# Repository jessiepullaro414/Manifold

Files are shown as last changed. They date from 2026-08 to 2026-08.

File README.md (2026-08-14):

# Manifold — KiCad schematic + PCB

Companion KiCad project for "Manifold", an Arduino Nano inspired (pinout/
form-factor only — not an official Arduino product, and not Arduino-IDE
compatible) 12V-powered board built from automotive/high-temp-rated parts
for engine-bay environments.

## Opening it

Open `Manifold.kicad_pro` in KiCad 6, 7, or 8. Everything the schematic needs
(all symbols) is embedded in `Manifold.kicad_sch` itself — no external symbol
libraries required to open and view it.

Both the schematic and `Manifold.kicad_pcb` are kept in KiCad's **current
native format** (not just an older-but-compatible one) — see "File format" below.

J1's footprint (TE AMPSEAL 776180-1) lives in this project too —
[`fp-lib-table`](fp-lib-table) registers it under the library nickname
`TE_AMPSEAL_776180-1`, pointing at [`footprints/TE_AMPSEAL_776180-1.pretty/`](footprints/TE_AMPSEAL_776180-1.pretty)
via `${KIPRJMOD}` (KiCad's "this project's folder" variable) — so it resolves
automatically for anyone who opens this project, without depending on where
it was originally downloaded to.

Same pattern on the schematic side: [`sym-lib-table`](sym-lib-table) registers
this project's own custom parts under the nickname `Manifold`, pointing at
[`Manifold.kicad_sym`](Manifold.kicad_sym) (both regenerated by `build_schematic.py` -
don't hand-edit either). The schematic still embeds every symbol inline too
(so it opens/nets fine even without this), but a real external library file
is what lets KiCad's own "Add Symbol" browser find `Manifold:*` parts, and is
what a from-scratch `kicad-cli sch erc` needs to not flag every single part
as "library not included in configuration".

## Building it

[`build.py`](build.py) runs the whole real pipeline in order — schematic
generation, PCB placement, autorouting, DRC — the same four scripts
described in "Routing it" and "How the schematic is built" below, just
chained together:

```
python build.py                 # full pipeline
python build.py --skip-route    # skip the slow FreeRouting pass
```

## Checking it

[`run_drc.py`](run_drc.py) runs `kicad-cli pcb drc` against `Manifold.kicad_pcb`
(or any other `.kicad_pcb` passed as an argument) and prints a readable report from
the JSON it produces — unconnected-item count (expected on this unrouted board) plus
every other violation type, grouped, with the actual offending items and positions,
not just per-type counts. `build_pcb.py` also runs DRC as its own last step, but only
prints counts; reach for this when you need the detail behind one of those counts.

```
python run_drc.py
python run_drc.py path/to/other.kicad_pcb
```

`kicad-cli sch erc Manifold.kicad_sch` is the schematic-side equivalent.
It went from **388 violations to 4** during a real triage pass (not just a
recount) - see "Rotated-footprint pad shapes" below and
[[kicad-file-generation-gotchas]] for the technical detail on each fix:

- 259 `endpoint_off_grid` - every symbol placement now snaps to KiCad's
  0.05in (1.27mm) schematic grid.
- 70 `lib_symbol_issues` - added a real `Manifold.kicad_sym` + `sym-lib-table`
  entry (this project's custom parts were only ever embedded inline in the
  schematic before, with no external library file backing them - fine for
  KiCad to open/net-list, not fine for its "library not found" check or for
  inserting a fresh instance from the symbol browser).
- 25 `label_dangling` + 25 `no_connect_connected` - U1's 25 spare MCU pins
  now get a real no-connect flag instead of a same-named, inherently
  one-off local label.
- 3 `isolated_pin_label` - same fix, applied to 3 individually-unused pins
  elsewhere (U2's PG, U4's NC, J2's NC) via a new `('nc',)` `place()` mode.
- 1 `pin_to_pin` - J1's +5V/+3V3 pins were typed `power_out` (implying the
  *connector* generates power), conflicting with U4's real LDO output on
  the same net - retyped `passive` (a connector pin exposing a rail isn't
  a second source of it).

**The remaining 4 are genuine, expected ERC characteristics, not bugs** -
each one is ERC's pin-type-based "is this driven?" check failing to trace
through a passive network or off-board source, not a real missing
connection:

- `+5V`, `VDDA`, and U2's `VIN` each show `power_pin_not_driven` because
  their real source sits on the far side of an LC filter (L1), a ferrite
  (L2), or a MOSFET (Q1) - none of which have a `power_out`-type pin to
  point to, since ERC doesn't trace continuity through passives.
- J2's `SWCLK` shows `pin_not_driven` because it's genuinely driven
  off-sheet, by an external debug probe.

If you regenerate and see anything **other than these same 4**, treat it
as a real regression, not baseline noise.

## Buck feedback divider - a real bug found in final review

R2/R3 (U2's FB divider) used to be 10k/3.3k, solving TI's own formula
(`Vout = VREF x (RFBT/RFBB + 1)`, VREF = 1V nominal per LMR33630-Q1's
datasheet Section 8.2.2.3) to **~4.03V, not 5V** - a real, roughly-1V-low
output, not a rounding nitpick. This mattered because that rail is exposed
on J1 as a Nano-compatible +5V pin for **external peripherals** - anything
expecting real 5V plugged into it would have been under-powered or
malfunctioned outright, and it ate into U4's LDO dropout margin too.

Fixed by solving for RFBB with RFBT held at 10k: `10k / (5V/1V - 1) = 2.5k`,
using the nearest standard E96 value, **2.49k** - which is suspiciously
exactly TI's own worked-example RFBB (24.9k, for their 100k/24.9k 5V
divider) scaled down by 10x, suggesting 3.3k was a substitution/typo
somewhere rather than a deliberate choice. New value gives ~5.02V.

## File format

`kiutils` (the library both generators use) writes the older v6-era schema by
default — version `20211014`, generator `kiutils`, unquoted UUIDs, no
`generator_version` field. KiCad opens that fine, but flags schematics as
needing conversion, and that would reappear every time either generator
regenerates its file.

Fixed at the source rather than worked around: both generators' last step
shells out to `kicad-cli sch upgrade` / `kicad-cli pcb upgrade` — KiCad's own
real format converter — on the file they just wrote. If `kicad-cli` isn't
found on your machine, the scripts still finish and print a note — the files
just won't be pre-upgraded.

## The PCB: what's real, what's placeholder, what's routed

[`build_pcb.py`](build_pcb.py) reads the schematic + a fresh `kicad-cli`
netlist export and generates `Manifold.kicad_pcb`: every part's **real**
footprint (loaded from its actual `.kicad_mod` file, not reinvented), with
every pad assigned the net the schematic says it should have.

**What this does NOT do: route copper.** Placement gives a compact starting
point, but this is a netlist-correct *unrouted* board — the same state
"Update PCB from Schematic" leaves you in before you route it yourself.

**Placement is a real 2D bin-pack, not a row of parts.** All 27 small parts
go through a single **skyline bin-packer**: it maintains a height profile
across the board's full width (fixed by J1 regardless of how tightly the
small parts pack — J1 is 20-40x bigger than everything else, so it, not the
small parts, sets the real width floor) and places each part wherever it
produces the lowest resulting top edge — trying *every* part both unrotated
and rotated 90°, not just a designated subset. Since greedy bin-packing is
order-dependent (which part gets considered first changes the whole
resulting layout), `best_skyline_pack` runs it with 5 different orderings
(largest-area, longest-side, tallest, widest, largest-perimeter first) and
keeps whichever actually produced the shortest board — cheap to do exhaustively
for 27 parts, and not something a single fixed heuristic can guarantee on
its own. Board is currently ~83×61mm, down from an initial ~142×88mm
row-based layout.

**Diminishing returns, checked quantitatively, not just eyeballed:** after
this rewrite, a per-mm-column height profile across the packed region shows
almost the *entire* width already sitting at or near the maximum height —
not one big rectangular gap like before, but a tightly-filled, slightly
uneven skyline. That's because U1 (the MCU - at the time, still the
placeholder LQFP48 footprint; see "U1's pinout" below for why that was
wrong and what replaced it) was 10.3×10.3mm — by far the single biggest
part — and its own footprint+margin
already accounts for most of the packed region's height on its own,
regardless of what gets stacked around it. Forcing U1 to place *last*
instead of first (an explicit experiment, not a guess) made the board
*worse* (21.0mm packed height vs. 13.6mm) because all the good low spots
were already taken by the time U1 needed one. Clustering the MCU's own
decoupling caps (100nF/1uF) physically next to it is genuinely good
practice for the real routed board's signal integrity, but in this
bounding-box model it wouldn't shrink the board further, since U1's own
footprint already sets the height floor no matter which parts sit next to
it.

**A second real bug, found by comparing against a manual rearrangement:**
after seeing this layout, the user manually spread the small-parts grid out
further in the KiCad GUI and saved the file - reading those exact saved
coordinates back out (`(at x y angle)` per footprint, regex-extracted since
kiutils can't re-parse a KiCad-saved file - see gotchas doc) showed their
arrangement using ~78mm of width to reach ~10.8mm of height, meaningfully
shorter than the script's own ~74.6mm-wide, ~12.2mm-tall result at the time.
The packer was handing itself less room than it actually had: `pack_width`
was `j1_width - 2*BOARD_MARGIN`, reserving a *second* margin on the right of
the small-parts grid on top of the margin baked into `board_width`'s own
`max(used_w, j1_width) + 2*BOARD_MARGIN` formula. Since board width is
already going to be at least `j1_width + 2*BOARD_MARGIN` regardless, giving
the packer up to the full `j1_width` costs nothing as long as it stays
within that - fixed by setting `pack_width = j1_width` outright. A width
sweep (72-95mm) confirms `j1_width` is the actual area-minimizing choice for
this part mix, not an arbitrary pick: going wider trims a little more
height but grows board width faster than that saves. Board dropped from
83.4×62.4mm to 83.4×61.0mm on this fix alone - free, since the board was
already going to be at least that wide.

The manual arrangement still edges out the automatic packer somewhat
(~10.8mm vs ~12.2mm content height) - most likely because a human doing
this by eye can look at the whole board and backtrack, where the packer
commits to each part's position in one greedy left-to-right pass and never
revisits it. Closing that remaining gap would need a fundamentally
different search (backtracking or exhaustive), not just another ordering
heuristic - tried 8 orderings x 11 width targets in a grid search and the
result barely moved (60.92mm best vs 61.0mm), confirming this is a real
plateau for the current greedy-heuristic family, not a tuning oversight.

This replaced an earlier two-block design (a fixed "actives" column next to
a "caps" grid, sized by a pre-computed proportional-area split, with small
headers optionally dropped into whatever rectangle the split left over).
That design couldn't reach real density: caps are small and uniform and
pack far more efficiently per mm² than the actives, so even a "correct"
area-proportional width split still left the caps block *shorter* than the
actives column, and the leftover rectangle only fit parts that happened to
match its exact shape — real open board space stayed open, which is exactly
what got flagged when reviewing a render. A single shared skyline profile
lets any part drop into any low spot next to any neighbor, not just its own
block's slice, which is what actually closes gaps like that.

**A real rotation bug was caught verifying this one.** The 90°-CCW local
coordinate transform `(x,y) → (-y,x)` used everywhere rotation was needed —
in the packer's own placement math *and* in the pre-write overlap-check
verification, so both sides agreed with each other — turned out to be
backwards for KiCad's actual rotation direction (`(x,y) → (y,-x)`). Because
both sides used the same wrong formula, the script's own overlap assertion
never caught it — it was internally consistent, just wrong. It surfaced
instead as a real, tiny (0.015-0.18mm) pad-to-pad `clearance` and
`shorting_items` DRC violation between a rotated pin header (J3) and a
neighboring IC (U2), where the rotated header's far pads landed almost on
top of the IC's pads instead of facing away from it. Confirmed by manually
computing where kicad-cli's real DRC said those specific pads actually were,
which only matched the `(y,-x)` transform. This is the reason bugs like this
get caught by `kicad-cli`'s real DRC and not just the script's own geometry
checks — two internally-consistent code paths agreeing with each other is
not the same as either of them being correct.

Three more real bugs were found and fixed while doing this work:

- **Footprint bounding boxes were pad-only**, undercounting parts like J1 —
  a right-angle through-hole connector whose silkscreen/body outline extends
  well past its pad positions. This produced margins that looked fine on
  paper but caused real `silk_edge_clearance` and `courtyards_overlap` DRC
  errors at tight spacing. Fixed by including silkscreen graphics (lines,
  polys, arcs) in the bbox calculation, not just pads — after which margins
  could go back down to their intended tight values and every clearance
  error disappeared.
- **Every part showed as "REF\*\*"** in DRC reports and the 3D viewer,
  because only the silkscreen *text* was being updated (`fp.graphicItems`),
  not the separate `fp.properties["Reference"]`/`["Value"]` dict that KiCad's
  own tools (DRC, BOM, 3D view) actually read from. Fixed by setting both.
- **Every reference designator sat dead center on its own part, on top of
  its own pads** (`silk_over_copper` x58, `silk_overlap` x35 in
  `kicad-cli pcb drc` - see [run_drc.py](run_drc.py) below). Root cause:
  kiutils' `Footprint.properties` is a plain `{name: value}` string dict - it
  has no field for a property's position, layer, or font, so `to_file()` can
  only ever write a bare `(property "Reference" "REF")` token, discarding
  whatever real position the *source* library footprint had. `kicad-cli pcb
  upgrade` then fills in the missing fields using KiCad's own built-in
  default *for that property name* - Reference defaults to `(at 0 0 0)` on
  `F.SilkS`, i.e. dead center - which is fine on a normally-spaced board but
  guarantees overlap at this board's 2mm part spacing. (Value/Datasheet/
  Description bare properties *don't* show up as silkscreen violations,
  because KiCad's defaults for those names are F.Fab/hidden, not visible
  silkscreen - so this was specifically a Reference-designator problem, not
  a general "properties are broken" problem.) Fixed by patching the written
  file's bare `(property "Reference" "REF")` tokens - exact string
  replacement, not regex, since the one-line form kiutils writes is exactly
  known at that point in the script, before `pcb upgrade` ever touches the
  file - with a real per-part position (just clear of that part's own bbox,
  reusing the same `footprint_bbox()` already used for placement) and a
  0.8mm font sized for 2mm part spacing instead of KiCad's normal 1.27mm
  default. Went from 96 DRC violations to 3 (the remaining 3 are an
  unrelated `lib_footprint_mismatch` finding - local footprint copies
  differing slightly from their library originals, not a silkscreen issue).

## Layer stackup: 4 layers

`board.layers` now declares `F.Cu`, `In1.Cu`, `In2.Cu`, `B.Cu` (verified
present in the generated file after `pcb upgrade`). In1 as a solid GND pour
and In2 as a +5V/+3V3 pour is standard practice for a board with a switching
buck regulator on it — shorter return paths, better EMI — and this board
already has one, so 4 layers is a sensible default rather than an arbitrary
choice. Exact dielectric thickness/material is left at KiCad's defaults; set
those in Board Setup if you have fab-specific requirements.

**The planes are now real, not just planned.** `route_board.py`'s
`add_and_fill_zones()` pours a solid **GND zone on In1.Cu** and a solid
**+3V3 zone on In2.Cu** (the primary MCU supply rail now that U1 runs
entirely on 3.3V — see "The MCU" below; +5V stays a normal routed trace,
since it's the lower-current Nano-compatibility rail feeding just J1's +5V
pin and the LDO input, not something else on this board depends on for a
low-impedance return path the way the buck regulator's GND loop does).

**Zones are added AFTER routing, not before — that ordering is load-bearing,
not a style choice.** The first attempt added the zone outlines in
`build_pcb.py`, *before* handing the board to FreeRouting, on the theory
that its Specctra DSN "plane" mechanism would let the autorouter treat
those layers as pre-claimed and route everything else around them. That
backfired two different ways:

1. **It made this already-tight board measurably harder to autoroute.** A
   solid zone covering an entire inner layer removes that layer's normal
   "just drop a via here" flexibility everywhere on the board, not only
   where the plane's own net actually needs it — and this board has a
   0.5mm-pitch 64-pin LQFP and a similarly tight VQFN-12 with very little
   room to spare already. Runs that reliably hit 0 unrouted nets before
   zones existed started leaving 1-4 stuck on the same few tight spots
   (U2's exposed-pad-to-pin connection, some U1-to-J1 nets) with zones
   present pre-route.
2. **Worse: FreeRouting would report "100% routed" while `run_drc.py` still
   found real "missing connection" findings** between GND/+3V3 pads (e.g.
   J1's THT pins) and the zone itself. The router had skipped drawing an
   explicit trace/via to some pads, assuming the plane would cover them —
   but the *actual* fill polygon, computed afterward and cleared around
   every other net's copper, didn't always reach every such pad. FreeRouting's
   own self-report and KiCad's real DRC were checking two different things,
   and only the second one is trustworthy — another instance of this
   project's running theme that a tool's own "success" claim isn't
   verification.

The fix: route the whole board as ordinary traces first — the same simple,
reliable regime that got 0 unconnected items before any zones ever existed —
and only *then* add the zones as purely additive copper on top of an
already-100%-connected board. Any GND/+3V3 trace or via the zone happens to
overlap becomes redundant (harmless), not the *only* connection, so there's
no longer any way for a pad to end up "connected only via a plane that
doesn't quite reach it." Pad connections are solid (`ZONE_CONNECTION_FULL`),
not thermal-relief spokes, for the same reliability reason — no spoke
geometry to fail, and this board isn't hand-soldered at a scale where
thermal relief's easier-rework benefit outweighs connection certainty.

**One more real bug along the way, a KiCad Python-scripting one, not a
design one:** filling both zones (different layers) in a single `pcbnew`
process reliably **segfaults** on the subsequent `board.Save()` — confirmed
directly by isolating each step (adding both zones: fine; filling both:
fine; only `Save()` afterward crashes, every time, only with two
different-layer zones present together). One zone filled and saved alone
never crashes. Root cause looks like a real threading/state bug in this
KiCad build's zone filler under scripting, not something to tune around via
zone settings — worked around by doing each zone in its own **separate**
`python.exe` subprocess (load → add one zone → fill → save), so the second
zone's process loads a file that already has the first zone's completed
fill baked in, and the two fills are never in memory together.

## Branding: the JessiesCars logo on B.SilkS

`build_pcb.py` places a real vector logo (badge + winged mark) on the back
silkscreen, sourced from [`both.kicad_sym`](both.kicad_sym) — a
`bitmap2component`-generated schematic symbol (29 polylines, ~1450 points,
traced from the real artwork, not anything this script invents). B.SilkS is
otherwise completely empty (nothing's mounted on the back), so it's placed
in J1's own footprint "shadow" — J1's bbox has a tall lower region below its
3 pad rows (its plastic housing outline) with zero pads or drills in it,
genuinely clear space rather than just visually-empty space a THT pad barrel
would poke through.

**Two coordinate-transform bugs, both caught by literally looking at the
render, not by DRC** (DRC has no way to know a logo is upside down or
backwards — this is a visual-correctness class of bug, not an electrical
one):

1. **Symbol space is Y-up, PCB board space is Y-down** — the exact same
   convention gotcha `build_schematic.py` already documents for placing
   symbol pins onto the sheet, easy to forget applies here too since
   `both.kicad_sym` is *also* a symbol-space file. Missing this flip put the
   whole logo upside down on the first attempt.
2. **A back-layer shape's stored coordinates are NOT auto-mirrored by
   KiCad** — only *text* gets a `mirror` flag (`Justify(mirror=True)`, see
   `kicad-file-generation-gotchas`); a plain polygon's points are used
   as-is, so artwork authored in normal (front-view) orientation reads
   backwards once the physical board is flipped over to view the back. Text
   needs the flag; polygons need their X coordinates negated by hand before
   placing, since they have no equivalent flag to set.

Both flips are real and both apply *together* (not either/or) — applying
only one produces a result that's wrong in a *different*, less obviously
"just mirrored" way (a 180° rotation, not a clean left-right flip), which is
exactly what the first attempt looked like: legible-ish but wrong letters
("CARZ" for "CARS"), not obviously backwards at a glance. Fixed by negating
*both* X and Y before scaling/placing. Verified by rendering the back side
(`kicad-cli pcb render --side bottom`) and reading the actual wordmark, not
just checking DRC — DRC-clean and visually-correct are different checks
here.

Same `gr_poly` gotcha as `gr_text` on the uuid front: kiutils' `tstamp`
field writes an unquoted `(tstamp xxxx)`, not the quoted `(uuid "xxxx")` a
real KiCad-written `gr_poly` has, and `kicad-cli` segfaults loading the file
without it — patched post-write, same pattern as the Reference-label and
credit-text fixes before it.

## Routing it

[`route_board.py`](route_board.py) routes the board with
[FreeRouting](https://github.com/freerouting/freerouting), the same way most
KiCad users do it manually: export a Specctra `.dsn`, autoroute it, import
the resulting `.ses` back, then pour the GND/+3V3 zones on top. Four steps,
run headless:

```
python route_board.py
python run_drc.py
```

1. **Export** — `pcbnew.ExportSpecctraDSN()`, called through KiCad's own
   *bundled* Python (`C:\Program Files\KiCad\10.0\bin\python.exe`, which has
   the real `pcbnew` module — different from the Python that runs the rest
   of this project's scripts). This is KiCad's real, tested exporter, not a
   reimplementation — `kicad-cli` doesn't expose DSN export at all (checked;
   its `pcb export` subcommand list has no `dsn`/`specctra` option), but the
   underlying scripting API does, and it's fully headless.
2. **Route** — `java -jar tools/freerouting-2.2.4.jar -de ... -do ... -mp 60
   -oit 0 --gui.enabled=false`. Requires Java (this project uses Eclipse
   Temurin 25 JRE) and the FreeRouting jar (57.8MB, not committed — see
   below).
3. **Import** — `pcbnew.ImportSpecctraSES()`, same bundled-Python mechanism,
   writes the routed tracks/vias back into `Manifold.kicad_pcb` and
   saves it.
4. **Pour zones** — GND on In1.Cu, +3V3 on In2.Cu, added and filled *after*
   routing (not before — see "Layer stackup" above for why that ordering
   matters and the real bugs skipping it caused), each in its own separate
   `python.exe` subprocess (also explained above — filling both in one
   process segfaults on save).

**Setup** (one-time): install a JRE, and download
[`freerouting-2.2.4.jar`](https://github.com/freerouting/freerouting/releases/tag/v2.2.4)
into `tools/`. The **jar**, not the installer — FreeRouting's own docs
specify the jar for headless/CLI use; the installers are for interactive
use only.

**Current result**: FreeRouting routes all 47 nets (103 pin-to-pin
connections, after U1's real 64-pin pinout replaced the old unwired
placeholder — see "U1's pinout" below) in 15-30 seconds — `run_drc.py`
confirms 0 unconnected items, same handful of pre-existing
`lib_footprint_mismatch` findings as before, nothing routing-related.

**The autorouter isn't perfectly deterministic run-to-run** — occasionally
it'll settle for 1-4 nets unrouted and stop (its own plateau-detection
gives up when a pass makes no further progress), rather than reaching 0
every single time. When that happens, just re-run `python route_board.py`
from a fresh `python build_pcb.py` (not on top of the partially-routed
board — re-routing incrementally on top of a stuck partial state hits the
same plateau again, since nothing about the board actually changed).
A second full-from-scratch attempt has reliably reached 0 unrouted so far.

**The inner layers are real planes now, not general routing layers** — see
"Layer stackup" above for the GND/+3V3 zone pours and the real bugs (a
routing-reliability regression and a scripting segfault) that showed up
getting there.

**U1 is fully wired now — no exceptions.** Earlier revisions of this board
left every one of U1's pads without a net, because its schematic pin numbers
were an unverified generic placeholder that didn't reflect any real chip's
actual pinout — wiring them to the real footprint's pads by number
coincidence would have produced confidently *wrong* connections, worse than
no connections at all. That's resolved: U1's pin numbers are now the real,
NXP-Reference-Manual-verified S32K144 64-pin LQFP pinout (see "U1's pinout"
above), so it gets normal net assignment like every other part.

Verified after generation, every time: no two footprints' bounding boxes
overlap, every net has the same pin count on the PCB as in the schematic (47
nets currently), and a real `kicad-cli pcb drc` pass comes back with zero
connectivity/footprint errors (only a benign "doesn't match library copy"
metadata nag on a handful of footprints that's just an artifact of embedding
them via script — re-running "Update Footprints from Library" in pcbnew
clears it).

**A real bug caught and fixed during this verification:** the AMPSEAL
connector's downloaded footprint uses KiCad's legacy *unquoted* pad-number
syntax, which `kiutils` parses as a Python `int` — silently failing every
net-lookup for that footprint (all pad numbers are stored as strings
everywhere else) until the lookup was fixed to normalize types. Before the
fix, J1 looked structurally fine (right pad count, right pattern) but
carried zero of its real net assignments.

## How the schematic is built

Every part uses a **generic placeholder symbol**: a rectangle body with pins.
For most parts (see below), the pin count/numbers/names are now **real**,
verified against actual manufacturer datasheets — not generic filler.

Connectivity uses three mechanisms, matching normal schematic practice:

- **Drawn wires** for the main signal flow: the 12V power chain (fuse →
  reverse-battery FET → buck), the MCU↔J1 signal bus, and the crystal.
- **Power symbols** (+5V, +3V3, GND, VIN) at every power-net connection point.
  Power nets deliberately never use local labels — mixing local labels with
  power symbols splits nets in KiCad.
- **Local labels** for shared or non-Nano-pinout signals: UART sharing D0/D1,
  the FB divider, VDDA/AREF/OSC taps, VCAP/BOOT_CAP for the two ICs that need
  an external charge-pump/bootstrap cap.

**Before you route a board from this:** swap the placeholder symbols for real
library symbols (matching what's now real about the footprints/pinouts) and
give it a visual tidy-up. Treat this as a correct **netlist and BOM skeleton**,
not a finished, review-ready schematic.

## Sections on the sheet

| Section | Refs | Notes |
|---|---|---|
| Power input & protection | F1, Q1, U3, D1, C1, C10 | Fuse, reverse-battery ideal-diode + FET, TVS clamp, charge-pump cap |
| 5V buck regulator | U2, L1, C2, R2, R3, C11, C12 | 12V (9–40V transient) → 5V. Now exists **only** for a Nano-compatibility 5V pin on J1 — the MCU itself no longer runs on this rail |
| 3.3V LDO | U4, C3 | Steps 5V → 3.3V, which is now the **primary MCU supply**, not just a spare pin |
| MCU core | U1, Y1, C4–C5, L2, R1 | NXP S32K144 automotive (real AEC-Q100 qualification), 8MHz placeholder crystal, reset pull-up, VDDA ferrite-filtered |
| Connectors | J1, J2, J3 | J1 = full Nano-pinout I/O on a **TE AMPSEAL 776180-1** (35-pos, right-angle, sealed), J2 = **SWD** (SWDIO/SWCLK/RESET), J3 = UART (shares D0/D1) |

Full component rationale lives in the design-spec document delivered
alongside this file — this schematic is the follow-through on that spec.

## The MCU: from ATmega328P → STM32 → NXP S32K144 (and losing "Arduino IDE")

This went through two real revisions, both driven by things that turned out
not to be true on closer inspection:

1. **ATmega328P → STM32L452xx**, because no automotive-qualified 5V-native
   Arduino-ish chip exists. This looked right at the time.
2. **STM32L452xx → NXP S32K144**, because it turned out mainstream STM32
   (Cortex-M) parts have **no AEC-Q100 qualification at all** — confirmed via
   ST's own community forum: *"not a single device in the standard STM32
   family meets the AEC-Q specs."* ST's real automotive 32-bit line (SPC5) is
   Power Architecture, not ARM, not Arduino-anything.

NXP's S32K1 family is genuinely AEC-Q100 qualified Arm Cortex-M4F. But:

- **This means giving up Arduino IDE support entirely** — not just the
  STM32duino alias-mapping caveat from before. NXP's own S32K144 EVB
  documentation is explicit: *"the NXP S32K144 is NOT natively supported by
  the Arduino IDE... development requires the dedicated S32 Design Studio IDE
  and the S32 Software Development Kit."* The "Arduino UNO pin layout"
  compatibility NXP markets is **physical only** — no `digitalWrite()`,
  `Serial`, or sketch-based workflow exists for this chip. Programming is via
  NXP's Eclipse-based IDE and an AUTOSAR-style SDK — a genuinely different,
  more automotive-industrial development workflow.
- **Still 3.3V logic, not 5V** — same consequence as before, unrelated to
  which 3.3V-logic chip is on the board. J1's dedicated +5V pin (unconnected
  to the MCU) remains the only genuine 5V on the board.

### U1's pinout: from placeholder to real, verified, and fully wired

**The 48-pin LQFP placeholder used until now was not just unverified — it
was wrong.** The S32K144 does not come in a 48-pin LQFP package at all.
Confirmed three independent ways against NXP's own S32K1xx Series Reference
Manual (Rev 8, 06/2018): S32K144's own pin-mapping sheet only has columns
for 64-LQFP/100-LQFP/100-BGA; sibling part S32K142's sheet is the same;
48-pin LQFP is a real NXP package, but it belongs to the smaller
S32K116/S32K118 sub-family (Cortex-**M0+**, not the M4F this board was
chosen for). **The real minimum package for S32K144 is 64-pin LQFP.**

Every earlier attempt at this (this session and prior ones) failed to fetch
the "pin table" because it isn't in the datasheet or Reference Manual's
visible text at all — NXP ships it as a spreadsheet
(`S32K144_IO_Signal_Description_Input_Multiplexing.xlsx`) embedded as a PDF
**file attachment** inside the Reference Manual, not as text or a table on
any page. Regular PDF text extraction (`pdftotext`, WebFetch) can't see it.
Pulled out directly with `pypdf`'s attachment API once a mirror that wasn't
blocking the download was found (Farnell, not Mouser/NXP/community.nxp.com —
all three of those still 403/timeout).

With the real, verified 64-pin table in hand, **U1 is now fully wired** —
no more placeholder, no more unwired pads:

- **58 real GPIO pins**, of which 5 keep their real default (reset-state)
  function matching how this board already used them: pin 11 (PTB7/EXTAL)
  and 12 (PTB6/XTAL) → the crystal, pin 62 (PTC4/SWD_CLK) and 64
  (PTA4/SWD_DIO) → the SWD header, pin 63 (PTA5/RESET_b) → reset.
- **VREFH (pin 9, the real ADC voltage-reference pin) goes to J1's AREF** —
  not a placeholder GPIO. AREF on a real board should reach the actual
  reference input, and now it does.
- **D0–D19 (20 pins, up from the placeholder's 14)** and **A0–A7 (8 pins,
  specifically chosen from the 27 real GPIO pins with a genuine `ADCn_SEx`
  alternate function — "analog in" is a real capability here, not just a
  name carried over from Arduino)**. D14–D19 are new: J1's 6 previously-spare
  pins now carry them, so **all 35 of J1's positions are used, zero spare**
  (see "Nano-pinout I/O" below).
- The other **25 free GPIO pins** aren't wired to anything — J1 has no more
  physical positions left for them — and are marked `no_connect` on the
  schematic with their real pin numbers, not placeholder ones.
- **U1's PCB footprint is now the real bundled KiCad
  `Package_QFP:LQFP-64_10x10mm_P0.5mm`**, replacing the placeholder
  `LQFP-48_7x7mm_P0.5mm`. `build_pcb.py`'s old "leave U1 unwired, its pin
  numbers might be wrong" special case is gone — U1 gets normal net
  assignment like every other part now, because its pin numbers are real.

SWDIO/SWCLK were always real, universal Arm Cortex-M debug signals
regardless of vendor — that part of the old placeholder note held up.
There is no BOOT0-style pin on this family (that was STM32-specific).

## Four parts that got real, verified pinouts this session

While researching the MCU footprint, real datasheet research (TI and
Nexperia PDFs, pulled and parsed directly) turned up genuine errors in four
other parts — now fixed with real pin numbers, not generic placeholders:

- **U2 (buck regulator):** LMR33630-Q1's real package is **VQFN-HR-12
  ("RNX0012C", 2×3mm body, ≤1mm height)** — it was never offered in
  HTSSOP-16 at all, which is what the schematic originally specified. Real
  12-pin table verified against TI's datasheet Table 5-1: symmetric
  VIN/PGND pairs for EMI cancellation, NC(3) tied to SW per the datasheet's
  own instruction, BOOT(4) needs a cap to SW (added: C11), VCC(5) is an
  internal 5V rail needing its own decoupling cap (added: C12), PG(8)
  unused here. **This package has no exposed pad at all** — an earlier
  version of this file (and the schematic) had a 13th "EP" pin tied to
  GND, which was wrong and has been removed; TI's own Pin Functions table
  has no EP row for this variant. The footprint is custom-built (not a
  bundled KiCad part, and not the wrong-sized 4×4mm placeholder used
  earlier) — see [`build_u2_footprint.py`](build_u2_footprint.py) for how
  the land pattern was derived directly from TI's package drawing
  (4225021/C, 05/2022) and [`footprints/TI_RNX0012C_VQFN-HR.pretty/`](footprints/TI_RNX0012C_VQFN-HR.pretty)
  for the result. This package's pin layout is genuinely irregular — 4
  pins down each side, 3 along the bottom, and one larger single pin (SW)
  on its own at the top — not a simple 3-per-side QFN, so it's worth
  opening the footprint in KiCad's footprint editor at least once before
  fab to see the real shape.
- **U3 (ideal-diode controller):** the schematic originally specified
  **LM74670-Q1, which turned out to be the wrong part** — that's TI's
  controller for alternator/rectifier diode emulation, not reverse-battery
  protection. The correct, purpose-built part is **LM74700-Q1** ("Low IQ
  Reverse Battery Protection Ideal Diode Controller"), real 6-pin SOT-23
  (DBV) package, real pinout verified against TI's datasheet. It also needs
  an external charge-pump capacitor across VCAP and ANODE that the schematic
  never had — added as C10, now confirmed at **100nF** against TI's actual
  design guidance (section 10.1.1.2.3): "VCAP: Minimum 0.1uF is required;
  recommended value of VCAP(uF) >= 10 x CISS(MOSFET)(uF)". Q1's real Ciss
  (450pF for the current part, PMV37ENEA, per Nexperia's datasheet) makes
  the formula's own figure (4.5nF) far smaller than the flat 0.1uF minimum,
  so the minimum governs - matching TI's own 12V-battery-protection example
  circuit exactly. The original 10nF value was 10x under TI's stated
  minimum, not just an unconfirmed guess.
- **U4 (LDO):** real candidate **TLV733P-Q1** (AEC-Q100) is 5-pin SOT-23
  (DBV), not the 3-pin package originally assumed. Real pinout verified
  against TI's datasheet.
- **Q1 (MOSFET), resolved with a real part swap:** the original candidate,
  **Nexperia PMV230ENEA** (AEC-Q101, SOT-23, pinout Gate=1/Source=2/Drain=3,
  verified against Nexperia's datasheet), derated to 0.9A at 100°C ambient -
  genuinely *below* F1's fuse rating at the time (originally 1A - see "F1"
  below for why it's now 2A), meaning the MOSFET could overheat at F1's
  normal, non-fault operating current, not just a thin margin. Replaced with
  **PMV37ENEA**: same SOT-23/TO-236AB package, same pinout, same 60V VDS (no
  TVS/clamping rework needed) - but RDSon of 37-49mOhm (vs 176-222mOhm)
  gives 3.5A@25°C / **2.5A@100°C**, comfortably above F1's rating with real
  margin either way (1A originally, 2A now), AEC-Q101 qualified, -55 to
  175°C range. One minor, honestly-noted mismatch: PMV37ENEA's max Vth
  (2.7V) is slightly above LM74700-Q1's own stated preference ("2V to 2.5V
  maximum") for its light-load regulation scheme - not a hard limit, worth
  a bench check at light load before final part lock.

A real geometry bug was also caught and fixed while wiring these up: a GND
power connection's extra riser wire landed exactly on a neighboring pin's own
stub, silently shorting that pin's real net onto GND. Caught via `kicad-cli`
netlist diff (an entire net had vanished), fixed, and now checked
automatically on every regeneration (`build_schematic.py` asserts no two
different net labels ever land on the same coordinate).

## AEC-Q100 / Q101 / Q200 grade key

Every part's `Value` field on the sheet is tagged with its actual automotive
qualification:

- **Q100 G1** = AEC-Q100 Grade 1 (−40°C to 125°C) for *integrated circuits*:
  U2 (buck), U3 (ideal-diode controller), U4 (LDO) — all TI, all verified.
  U1 (MCU) carries **AEC-Q100** (no grade suffix, since the exact grade for
  this NXP family wasn't independently confirmed this session).
- **Q101** = AEC-Q101, for *discrete semiconductors*: Q1 (MOSFET), D1 (TVS).
- **Q200** = AEC-Q200, for *passives*: Y1, C1–C13, R1–R3, L1, L2.
- **F1 (fuse) and J1–J3 (connectors) intentionally have no AEC-Q tag** — those
  categories aren't covered by the AEC-Qxxx family at all; they're qualified
  against their own standards (SAE J2077 / ISO 8820-3 for F1's real Littelfuse
  297 MINI automotive blade fuse, connector-specific automotive standards for
  J1-J3). Don't read the missing tag as an oversight.

## Footprints (for "Update PCB from Schematic")

Every footprint field is a real KiCad library reference, checked directly
against the actual `.kicad_mod` files (not just typed from memory):

- F1: Keystone 3568 Mini blade fuse holder (`Fuse:Fuseholder_Blade_Mini_Keystone_3568`,
  bundled directly in KiCad, 3D model included) - a traditional, physically
  replaceable automotive blade fuse, not a soldered-down SMD fuse. See
  "F1: traditional blade fuse" below for why.
- U2: real, custom-built VQFN-HR-12 footprint (`TI_RNX0012C_VQFN-HR:TI_RNX0012C_VQFN-HR-12_2x3mm_P0.5mm`)
  — see above and [`build_u2_footprint.py`](build_u2_footprint.py).
- U3: real SOT-23-6 (bundled).
- U4: real SOT-23-5 (bundled).
- Q1: real SOT-23 (bundled).
- J2: `Tag-Connect_TC2030-IDC-NL...` — note the hyphen KiCad's real file uses
  (`Tag-Connect`, not `TagConnect`).
- **J1 is fully resolved, including a real dimensional check:** **TE
  Connectivity AMPSEAL 776180-1** — 35-position, 3-row, 4mm pitch,
  right-angle through-hole, sealable, −40°C to 125°C / IP67. Its footprint
  was downloaded from
  [SnapEDA](https://www.snapeda.com/parts/776180-1/TE+Connectivity/view-part/)
  and copied into [`footprints/TE_AMPSEAL_776180-1.pretty/`](footprints/TE_AMPSEAL_776180-1.pretty)
  for project portability. Checked directly against TE's own real customer
  drawing (`ENG_CD_776180_J.pdf`, fetched from `te.com`'s document-delivery
  system, sheet 2's "RECOMMENDED P.C. BOARD LAYOUT" - a real, dimensioned
  engineering drawing, not the datasheet's summary page): pin drill
  (Ø1.75mm), pin pitch (4mm), row stagger (2mm), mounting-hole diameter
  (Ø2.85mm), and mounting-hole-to-mounting-hole span (57mm) all matched the
  downloaded footprint exactly. **One real, genuinely wrong dimension was
  found and fixed**: the two non-plated mounting holes were 0.5mm off in Y
  (at 4.5mm instead of 4.0mm) - TE's drawing shows them sitting exactly
  in-line with the middle pin row, not offset from it. Confirmed via the
  PDF's own vector geometry (mounting hole's crosshair falls exactly on the
  middle row's construction line), not just eyeballing the rendered page.
  Fixed directly in `TE_1-776180-1.kicad_mod` (a downloaded static library
  asset, not something this project's scripts generate from scratch, so a
  direct edit - not a generator script - is the right fix here).
- **U1 is fully resolved too** — see "U1's pinout" above. The footprint
  *was* the issue here (LQFP48 isn't a real S32K144 package at all), not
  just the pin-to-net mapping; both are fixed now, using the real
  Reference-Manual-verified 64-pin LQFP pinout and footprint.

## 3D models

Four parts had no 3D model showing in KiCad's 3D viewer, for three
different reasons:

- **J1** simply never had one — its footprint was a bare SnapEDA download
  (2D only). Fixed with a real manufacturer STEP file
  ([`1-776180-1.step`](footprints/TE_AMPSEAL_776180-1.pretty/TE_1-776180-1.step)),
  downloaded and supplied directly by the user, wired into
  `TE_1-776180-1.kicad_mod` with a `${KIPRJMOD}`-relative `(model ...)`
  block (same portability pattern as the footprint itself).
- **F1** (originally the Littelfuse NANO2 SMD fuse) had this same missing-
  model problem — its `(model ...)` reference pointed at
  `${KICAD10_3DMODEL_DIR}/Fuse.3dshapes/Fuse_Littelfuse-NANO2-451_453.step`,
  which doesn't actually exist in this KiCad 10 install (checked directly:
  the real `Fuse.3dshapes` folder has 28 files, none of them this one) - a
  real packaging gap in the bundled library, not a project bug. Moot now:
  F1 was later replaced entirely with a traditional Mini blade fuse holder
  (see "F1: traditional blade fuse" below) whose bundled model genuinely
  exists in this install, so no placeholder/workaround is needed for F1
  anymore at all.
- **U2**'s custom-built footprint (see above) never had a model at all,
  since it was hand-built from a datasheet rather than downloaded from a
  library that would normally ship one alongside it.
- **J2** (Tag-Connect TC2030-IDC-NL) is not a bug and got no model: its
  real footprint (checked directly against the bundled `.kicad_mod`) is 6
  bare `connect`-type pads plus 2 non-plated locating holes and nothing
  else — `attr exclude_from_pos_files exclude_from_bom` even marks it as
  not a placeable, orderable part. The actual Tag-Connect hardware is a
  detachable pogo-pin cable head that's never mounted on the assembled
  board, so there's genuinely no physical body to model here.

U2's placeholder ([`build_3d_models.py`](build_3d_models.py), using
[`cadquery`](https://cadquery.readthedocs.io/) to write a real STEP file, not
just a KiCad-only format) is a real-dimension bounding box, not
manufacturer-exact art — good enough for a 3D-viewer sanity check and
clearance reasoning, not a photorealistic BOM render:

- U2: 2.0 x 3.0 x 1.0mm, the same real TI package-drawing dimensions
  already used to build the 2D footprint (`build_u2_footprint.py`).

## Rotated-footprint pad shapes (real KiCad/kicad-cli characteristic, not a script bug)

Building U2's real, densely-pitched (0.5mm) VQFN-HR footprint surfaced a
subtle, reproducible characteristic of how KiCad 10.0.4 handles a footprint
placed at a 90° rotation: the footprint's overall placement rotation (its
`(at x y 90)`) correctly rotates every pad's *position*, but does **not**
carry through to each pad's own *shape* for rendering or DRC purposes unless
that pad also has its own local rotation angle set to match. Confirmed with
a from-scratch, hand-written two-pad test footprint (no `kiutils` involved
at all) placed once at 0° and once at 90°: only the 90° copy showed a false
0mm-clearance "short," and adding an explicit `(at x y 90)` to each of its
pads (matching the parent's rotation) cleared it completely.

This had been silently affecting every rotated part on this board (R2, R3,
J3, Y1) since zone pours were added — invisible until now purely because
those parts' pads happen to be close enough to square that an
unrotated-vs-rotated shape swap doesn't change anything measurable. U2's
0.6×0.25mm pads were the first asymmetric enough to turn it into a real
`clearance`/`solder_mask_bridge` DRC failure. Fixed in `build_pcb.py`: every
rotated footprint now gets its pads' local angle set to match its own
placement angle, not just the footprint-level rotation. Confirmed fixed two
independent ways: the DRC violations themselves cleared, and `kicad-cli`'s
own unrelated `lib_footprint_mismatch` check (which normalizes for rotation
before diffing against the library copy) stopped flagging R2/R3/Y1/U2 as
"edited" once their pad angles matched their footprint's rotation.

## Board position on the page, and readable silkscreen/fab text

Two things fixed together, since both came from the same "everything sat at
board-local (0,0)" root cause:

- **The board was jammed in the page's top-left corner.** `Board.create_new()`
  defaults to an A4 landscape page (297x210mm), and the board's own Edge.Cuts
  outline started at (0, 0) - which is also the page's own top-left corner.
  Fixed with a single centering offset (`BOARD_OFFSET_X/Y` in `build_pcb.py`),
  computed once and applied to every already-computed placement (parts,
  Edge.Cuts, the back-silkscreen logo) - not a rework of the packer itself,
  which still places everything relative to a (0, 0) corner, just a corner
  that now sits in the middle of the page instead of flush against it.
- **Every part's Value text was overlapping, illegible.** KiCad's own default
  position for a bare `Value` property is one fixed offset applied
  identically to every part - fine on a loosely-spaced board, but this one's
  densely skyline-packed strip has many parts only 2-4mm apart, and strings
  like `SMCJ33A automotive (AEC-Q101)` are far wider than that at any
  legible font size. Unlike the Reference fix (clearing a part's own bbox is
  enough, since References are short), Value text needed checking against
  *neighboring* parts too. Fixed with a real greedy interval-scheduling lane
  assignment (sort parts left-to-right, place each Value label in the
  lowest lane whose last label doesn't overlap it, each successive lane a
  bit further from the board) plus a smaller font (0.5mm vs Reference's
  0.8mm) - see the block above `# 5b. Value-label lane assignment` in
  `build_pcb.py`. A third, unexpected source of the same problem turned up
  once Value stopped drowning it out: many bundled footprints (mostly the
  small passives) carry a `KiLib_Generator` metadata property (e.g.
  `SMD_2terminal_chip_molded`) that - unlike `Description`/`Datasheet` -
  does *not* default to hidden, and was rendering visibly at (0,0,0) on
  every part. It's pure footprint-wizard metadata, not documentation this
  board needs, so it's dropped outright rather than also lane-positioned.

## F1: traditional blade fuse, not SMD (2026-07-19)

User request: swap F1 to a traditional automotive fuse "to make it easier
for the user" (i.e. field-replaceable at any auto parts store, not a
soldered-down SMD part). Two real, separate parts now:

- **Holder** (soldered to the board): Keystone Electronics **3568**, a
  Mini-blade THT fuse holder, bundled directly in KiCad's own
  `Fuse.pretty` library (`Fuse:Fuseholder_Blade_Mini_Keystone_3568`) with
  its 3D model genuinely present in this install - no missing-model
  workaround needed here, unlike the old NANO2 footprint (see "3D models"
  above). Each of its 2 logical terminals has TWO physical THT pads
  (redundant solder joints for mechanical strength) - `build_pcb.py`'s
  net-vs-schematic pin-count check had to be taught to dedupe by
  `(ref, pad.number)` rather than count every physical pad, since a real
  footprint can legitimately have more physical pads than logical pins.
- **Fuse** (the swappable/replaceable part, not itself a PCB footprint):
  Littelfuse **297 series MINI**, real SAE J2077 / ISO 8820-3 automotive
  qualification.

**Rating bumped from 1A to 2A**: traditional blade-style automotive fuses
don't come in a 1A rating at all - 2A is the lowest standard rating in
this real fuse family (confirmed by checking Littelfuse's own MINI-series
color-code chart, which starts at 2A/gray). Confirmed this doesn't strain
anything else in the design: Q1 (PMV37ENEA) already had 2.5A@100°C
headroom from its earlier swap (see "Q1" above), comfortably clearing a 2A
fuse the same way it cleared the original 1A one.

Board grew from 83.4x35.2mm to 83.4x36.5mm - the Mini blade holder's real
footprint (16.5 x 7.24mm) is substantially bigger than the SMD NANO2
footprint it replaced, but the skyline packer absorbed almost all of the
size difference by repacking, not by growing the board 1:1 with the part.

One rendering quirk worth knowing, not a real defect: from directly
overhead in KiCad's 3D viewer, F1 can appear to visually disappear behind/
under J1's connector body, and from a steep low-angle view can even look
like it's nested inside J1's shroud. Checked directly (removed J1 from a
scratch copy of the board and re-rendered; separately, compared both
parts' real absolute footprint bounding boxes in Python) - the two don't
actually overlap (a clean 10.4mm gap in Y between them). It's J1's 3D
model's mounting-boss geometry visually covering that screen region from
certain angles, a camera/rendering artifact, not a placement bug - DRC
confirms zero clearance violations either way.

## Case mounting: rounded corners + 2 screw holes (2026-07-19)

User request: round the board's corners and add 2 case-mounting screw
holes in the corners opposite J1.

- **Rounded corners**: `CORNER_RADIUS = 3.0` in `build_pcb.py`. Edge.Cuts
  is now 4 straight `GrLine`s (shortened by the radius at each end) + 4
  `GrArc` quarter-circles, one per corner - not just a cosmetic touch, a
  smaller stress-concentration point at a corner matters for a board this
  small and this thin. Applies to all 4 corners uniformly, including the
  two nearest J1 - checked that this doesn't interfere with J1's own real
  mounting holes or its "PCB EDGE" line (see the J1 edge-cutout section
  above); real clearance confirmed via DRC, not just eyeballed.
- **2 mounting holes (MH1/MH2)**: `MountingHole:MountingHole_3.2mm_M3`,
  a real bundled KiCad footprint (3.2mm NPTH clearance hole for an M3
  screw, no annular ring, `exclude_from_pos_files`/`exclude_from_bom`
  already set correctly by KiCad itself since it's mechanical, not an
  orderable part) - matches the M3 hardware size already used by J1's own
  AMPSEAL mounting bosses, for one consistent screw size across the whole
  assembly. Placed in the top-left/top-right corners - "the other side of
  the J1 plug" - 7mm in from each edge.
- **Real keepout, not a hopeful placement**: the skyline packer that
  places every small part now gets seeded with an *elevated starting
  height profile* at both ends (`initial_skyline` in `skyline_pack`/
  `best_skyline_pack`) sized to the mounting holes' own clearance need,
  so parts are placed with real knowledge these corners are reserved -
  the same lesson as J1's "PCB EDGE" fix earlier: a keepout has to be a
  real input the placer respects, not a hope nothing lands there followed
  by a DRC scramble. Board grew slightly to accommodate the reserved
  corners: 83.4x36.5mm -> 83.4x38.7mm.
- **One real bug hit and fixed**: MH1/MH2's bundled footprint already has
  a sensibly-positioned Reference label in the library file, but
  `fp.properties["Reference"] = ref` (kiutils' bare-string-only property
  dict) silently drops that position, so it fell back to KiCad's own
  `(0,0,0)` default - landing right on top of the hole itself (confirmed
  via a real `silk_over_copper` DRC hit). Same fix as every other part on
  this board: feed the real intended offset into `ref_label_pos` so the
  existing Reference-repositioning patch picks it up too.

## Known gaps / things to verify before fab

- Placeholder symbols are not visually polished — expect to reposition
  property text and swap in real library symbols for a presentation-quality
  sheet.
- BOM part numbers and distributor links were researched and verified
  live (Digi-Key/Mouser) for every line - real AEC-Q100/Q101/Q200-qualified
  parts throughout, with two known exceptions: (1) R3 (2.49k, 0603,
  Yageo AC0603FR-072K49L)'s exact part number is very likely real (matches
  the confirmed-live neighboring E96 values in the same series) but no
  live distributor page could be loaded for it specifically - verify
  before ordering; (2) confirm current stock/pricing hasn't changed since
  this was last checked, since distributor stock/pricing is a moving
  target.

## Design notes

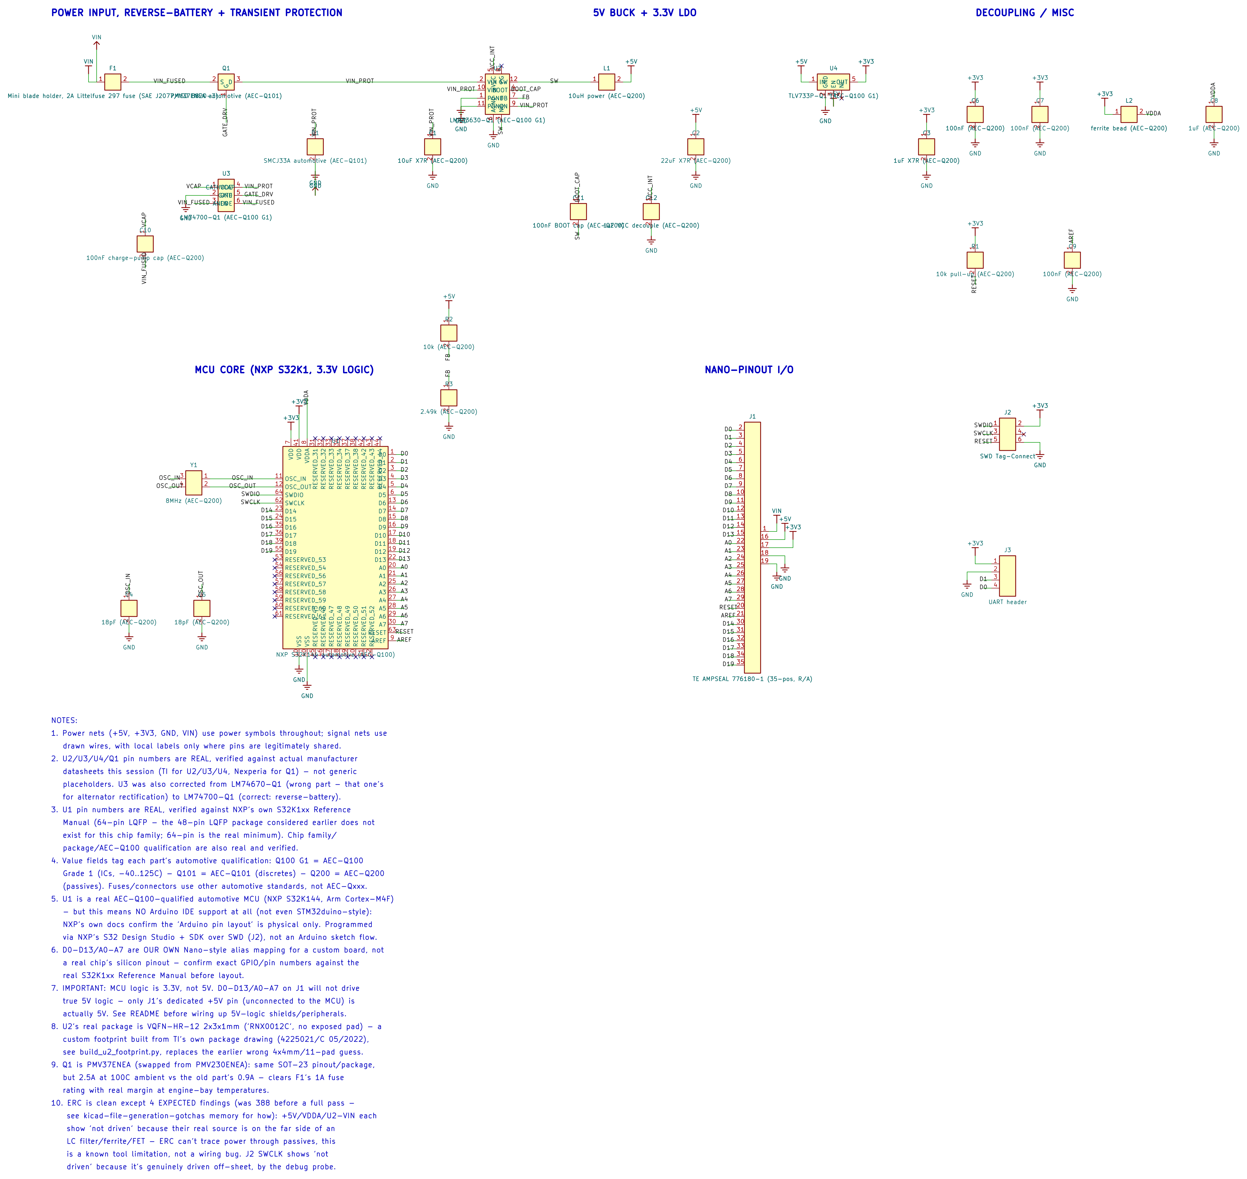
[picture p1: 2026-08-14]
Manifold_schematic.png

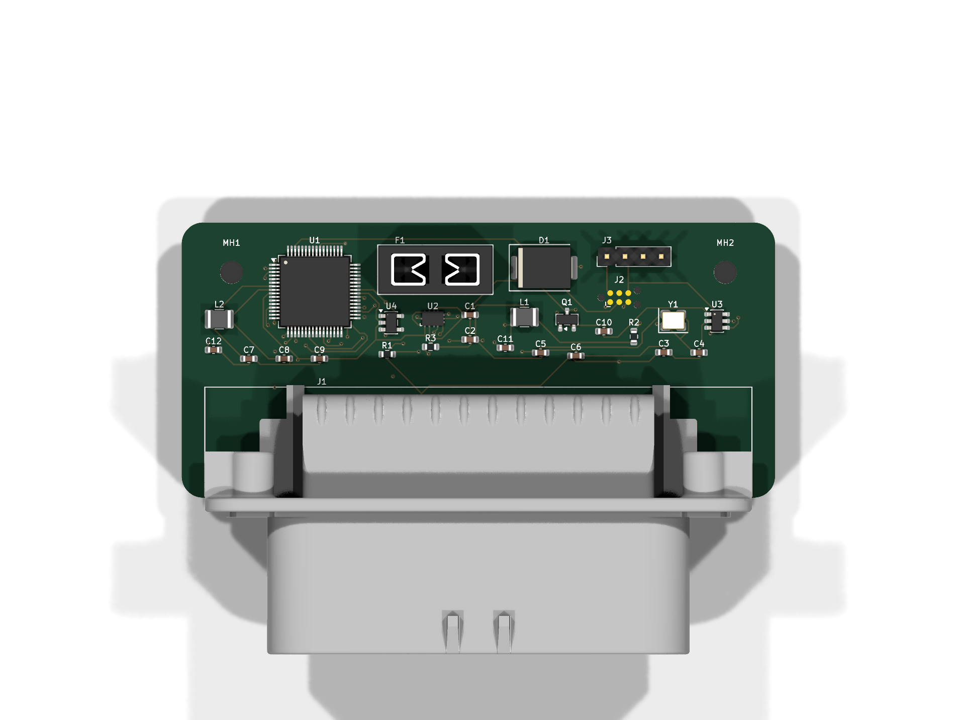
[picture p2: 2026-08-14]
manifold_top.png

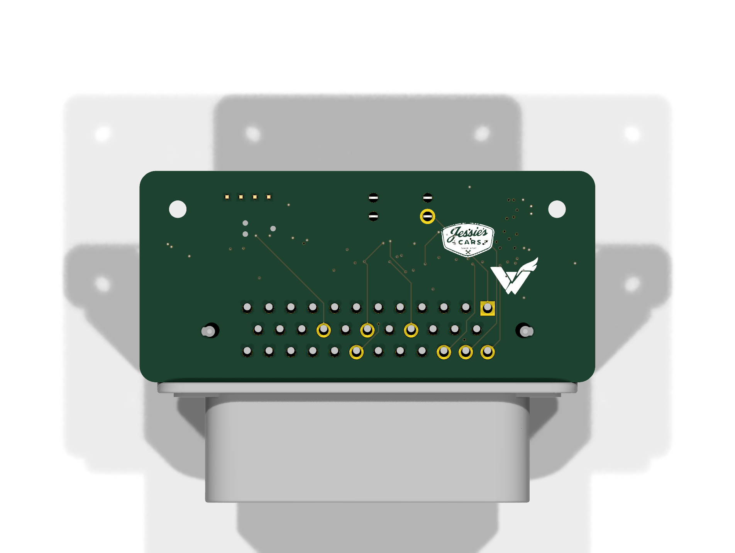
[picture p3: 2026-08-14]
manifold_back.png

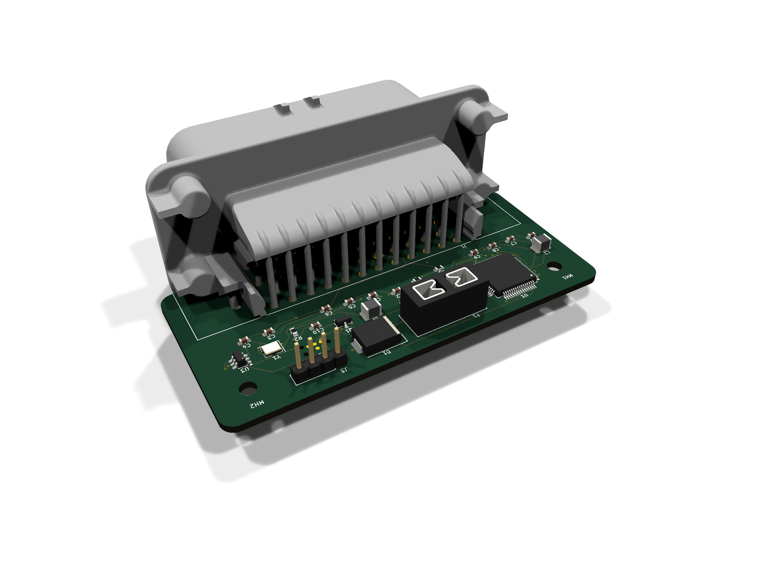
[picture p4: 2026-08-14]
manifold_angle2.png

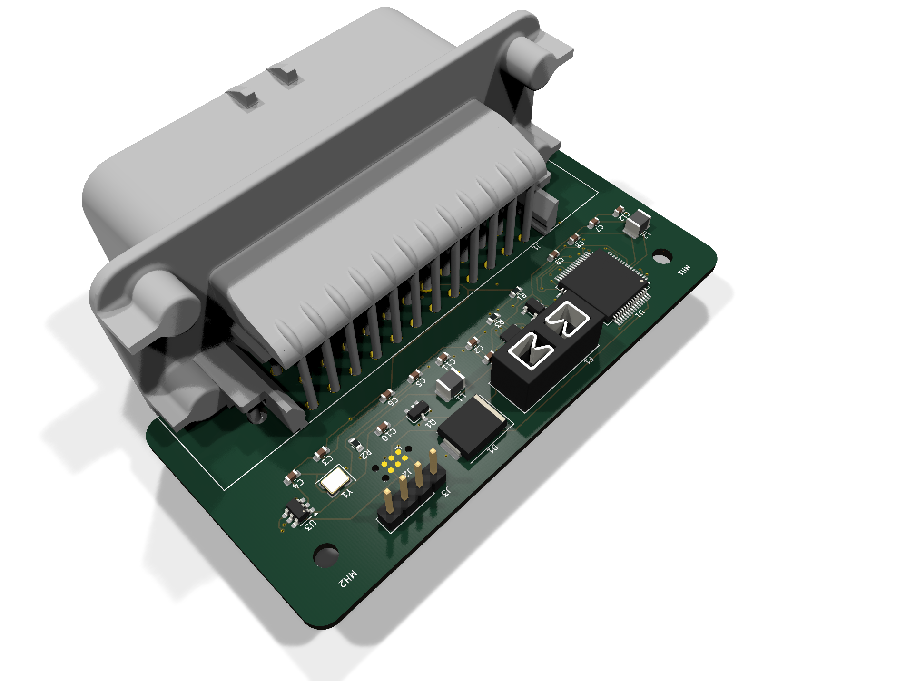
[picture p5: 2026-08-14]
manifold_hero.png

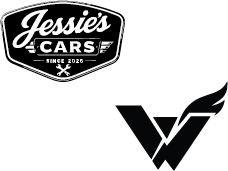
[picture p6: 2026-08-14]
both.png

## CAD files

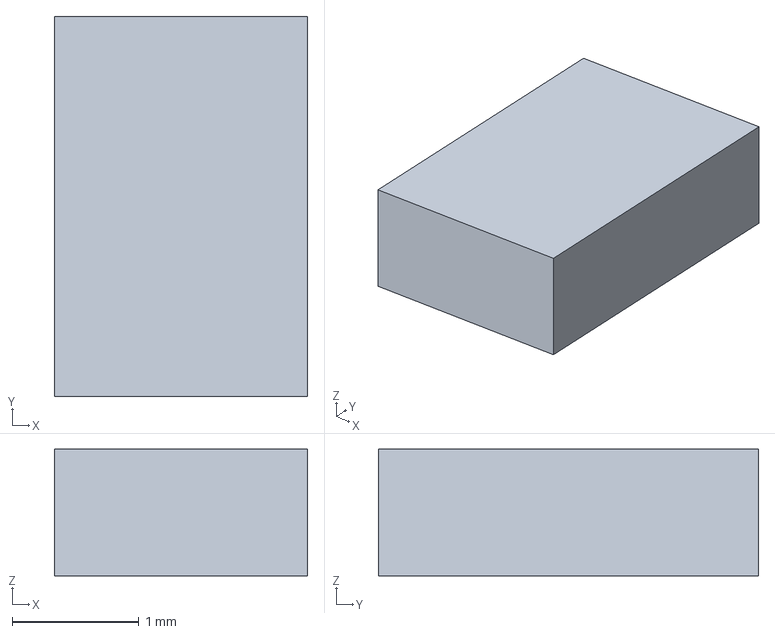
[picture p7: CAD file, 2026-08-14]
3dmodels/TI_RNX0012C_VQFN-HR-12_2x3mm.step
2.00 x 3.00 x 1.00 mm

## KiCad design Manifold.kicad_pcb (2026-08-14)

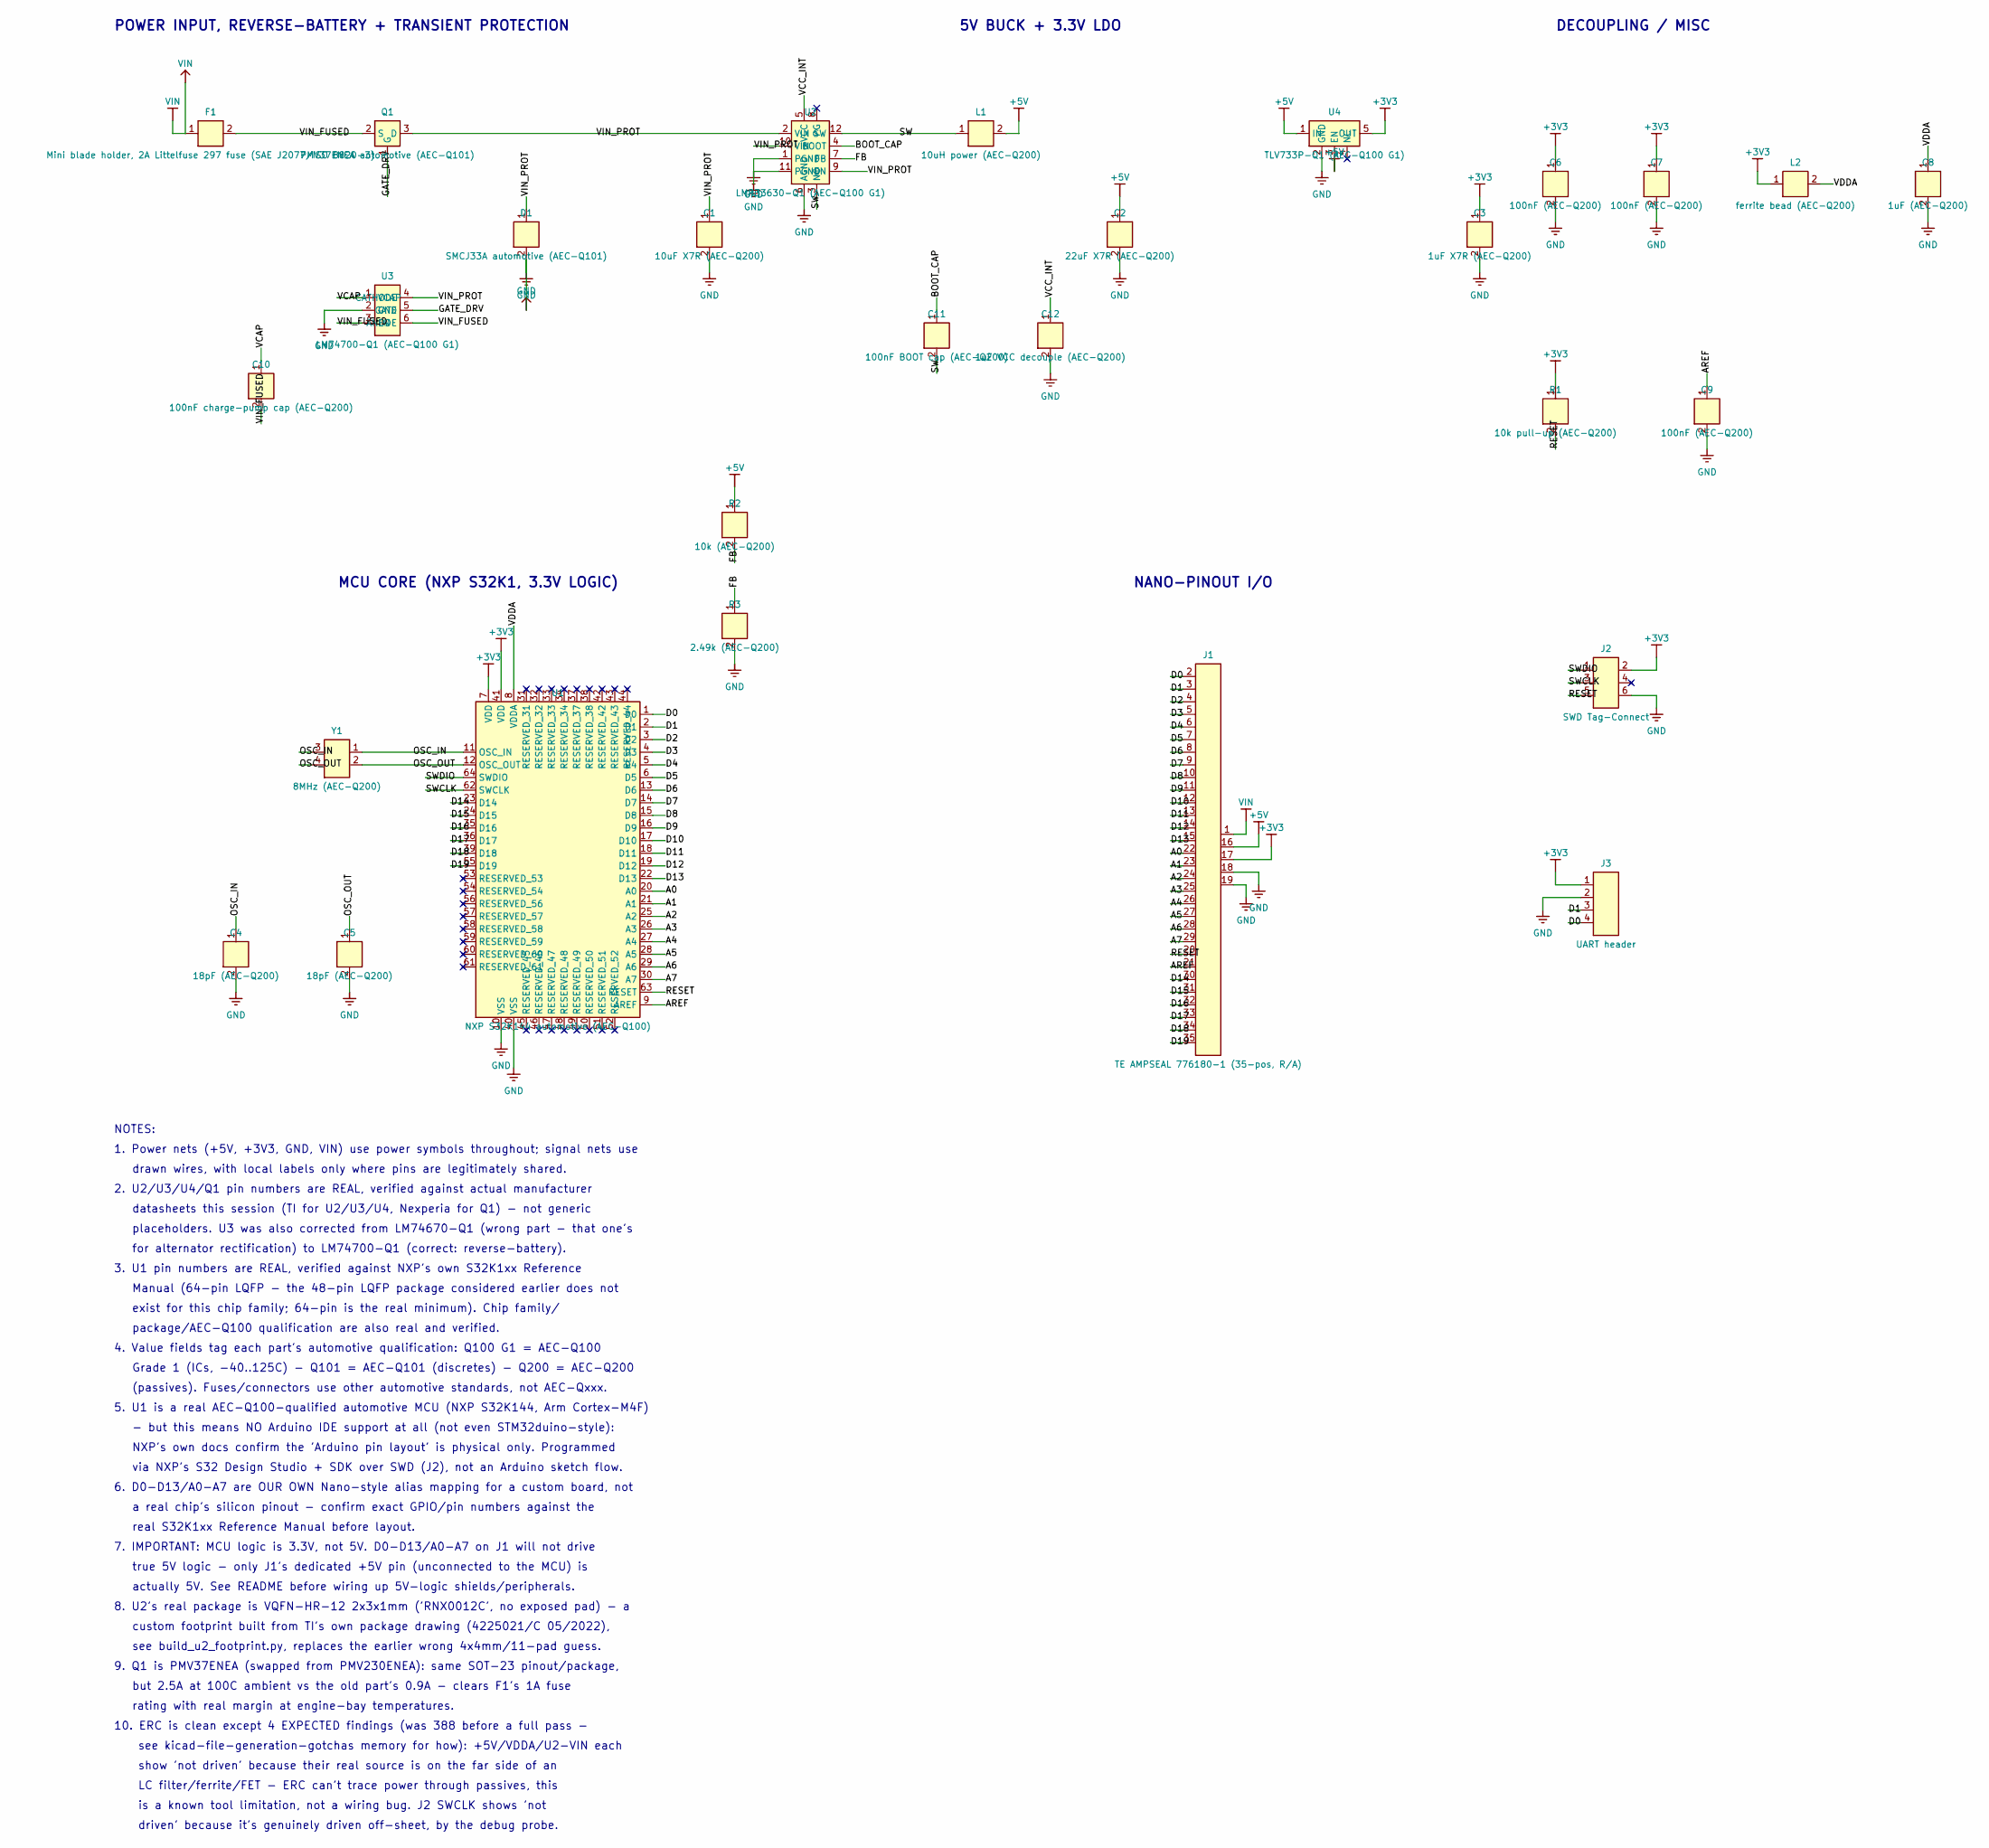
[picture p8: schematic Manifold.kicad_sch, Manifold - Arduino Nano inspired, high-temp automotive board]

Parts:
C1: 10uF X7R (AEC-Q200); C_0603_1608Metric
C2: 22uF X7R (AEC-Q200); C_0603_1608Metric
C3: 1uF X7R (AEC-Q200); C_0603_1608Metric
C4, C5: 18pF (AEC-Q200); C_0603_1608Metric
C6, C7, C9: 100nF (AEC-Q200); C_0603_1608Metric
C8: 1uF (AEC-Q200); C_0603_1608Metric
C10: 100nF charge-pump cap (AEC-Q200); C_0603_1608Metric
C11: 100nF BOOT cap (AEC-Q200); C_0603_1608Metric
C12: 1uF VCC decouple (AEC-Q200); C_0603_1608Metric
D1: SMCJ33A automotive (AEC-Q101); D_SMC
F1: Mini blade holder, 2A Littelfuse 297 fuse (SAE J2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; Fuseholder_Blade_Mini_Keystone_3568
J1: TE AMPSEAL 776180-1 (35-pos, R/A); TE_1-776180-1
J2: SWD Tag-Connect; Tag-Connect_TC2030-IDC-NL_2x03_P1.27mm_Vertical
J3: UART header; PinHeader_1x04_P2.54mm_Vertical
L1: 10uH power (AEC-Q200); L_1210_3225Metric
L2: ferrite bead (AEC-Q200); L_1210_3225Metric
Q1: PMV37ENEA automotive (AEC-Q101); SOT-23
R1: 10k pull-up (AEC-Q200); R_0603_1608Metric
R2: 10k (AEC-Q200); R_0603_1608Metric
R3: 2.49k (AEC-Q200); R_0603_1608Metric
U1: NXP S32K144 automotive (AEC-Q100); LQFP-64_10x10mm_P0.5mm
U2: LMR33630-Q1 (AEC-Q100 G1); TI_RNX0012C_VQFN-HR-12_2x3mm_P0.5mm
U3: LM74700-Q1 (AEC-Q100 G1); SOT-23-6
U4: TLV733P-Q1 (AEC-Q100 G1); SOT-23-5
Y1: 8MHz (AEC-Q200); Crystal_SMD_3225-4Pin_3.2x2.5mm

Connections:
+3V3: C3.1, C6.1, C7.1, J1.17 (+3V3), J2.2 (VCC), J3.1 (VCC), L2.1, R1.1, U1.7 (VDD), U1.41 (VDD), U4.5 (OUT)
+5V: C2.1, J1.16 (+5V), L1.2, R2.1, U4.1 (IN), U4.3 (EN)
A0: J1.22 (A0), U1.20 (A0)
A1: J1.23 (A1), U1.21 (A1)
A2: J1.24 (A2), U1.25 (A2)
A3: J1.25 (A3), U1.26 (A3)
A4: J1.26 (A4), U1.27 (A4)
A5: J1.27 (A5), U1.28 (A5)
A6: J1.28 (A6), U1.29 (A6)
A7: J1.29 (A7), U1.30 (A7)
AREF: C9.1, J1.21 (AREF), U1.9 (AREF)
BOOT_CAP: C11.1, U2.4 (BOOT)
D0: J1.2 (D0), J3.4 (RX), U1.1 (D0)
D1: J1.3 (D1), J3.3 (TX), U1.2 (D1)
D2: J1.4 (D2), U1.3 (D2)
D3: J1.5 (D3), U1.4 (D3)
D4: J1.6 (D4), U1.5 (D4)
D5: J1.7 (D5), U1.6 (D5)
D6: J1.8 (D6), U1.13 (D6)
D7: J1.9 (D7), U1.14 (D7)
D8: J1.10 (D8), U1.15 (D8)
D9: J1.11 (D9), U1.16 (D9)
D10: J1.12 (D10), U1.17 (D10)
D11: J1.13 (D11), U1.18 (D11)
D12: J1.14 (D12), U1.19 (D12)
D13: J1.15 (D13), U1.22 (D13)
D14: J1.30 (D14), U1.23 (D14)
D15: J1.31 (D15), U1.24 (D15)
D16: J1.32 (D16), U1.35 (D16)
D17: J1.33 (D17), U1.36 (D17)
D18: J1.34 (D18), U1.39 (D18)
D19: J1.35 (D19), U1.55 (D19)
FB: R2.2, R3.1, U2.7 (FB)
GATE_DRV: Q1.1 (G), U3.5 (GATE)
GND: C1.2, C2.2, C3.2, C4.2, C5.2, C6.2, C7.2, C8.2, C9.2, C12.2, D1.2, J1.18 (GND), J1.19 (GND), J2.6 (GND), J3.2 (GND), R3.2, U1.10 (VSS), U1.40 (VSS), U2.1 (PGND), U2.6 (AGND), U2.11 (PGND), U3.2 (GND), U4.2 (GND)
OSC_IN: C4.1, U1.11 (OSC_IN), Y1.1 (OSC_IN), Y1.3 (OSC_IN)
OSC_OUT: C5.1, U1.12 (OSC_OUT), Y1.2 (OSC_OUT), Y1.4 (OSC_OUT)
RESET: J1.20 (RESET), J2.5 (RST), R1.2, U1.63 (RESET)
SW: C11.2, L1.1, U2.3 (NC), U2.12 (SW)
SWCLK: J2.3 (SWCLK), U1.62 (SWCLK)
SWDIO: J2.1 (SWDIO), U1.64 (SWDIO)
VCAP: C10.1, U3.1 (VCAP)
VCC_INT: C12.1, U2.5 (VCC)
VDDA: C8.1, L2.2, U1.8 (VDDA)
VIN: F1.1, J1.1 (VIN)
VIN_FUSED: C10.2, F1.2, Q1.2 (S), U3.3 (EN), U3.6 (ANODE)
VIN_PROT: C1.1, D1.1, Q1.3 (D), U2.2 (VIN), U2.9 (EN), U2.10 (VIN), U3.4 (CATHODE)

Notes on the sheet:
placeholders. U3 was also corrected from LM74670-Q1 (wrong part - that one's
show 'not driven' because their real source is on the far side of an
NANO-PINOUT I/O
exist for this chip family; 64-pin is the real minimum). Chip family/
6. D0-D13/A0-A7 are OUR OWN Nano-style alias mapping for a custom board, not
DECOUPLING / MISC
8. U2's real package is VQFN-HR-12 2x3x1mm ('RNX0012C', no exposed pad) - a
4. Value fields tag each part's automotive qualification: Q100 G1 = AEC-Q100
but 2.5A at 100C ambient vs the old part's 0.9A - clears F1's 1A fuse
a real chip's silicon pinout - confirm exact GPIO/pin numbers against the
5V BUCK + 3.3V LDO
true 5V logic - only J1's dedicated +5V pin (unconnected to the MCU) is
- but this means NO Arduino IDE support at all (not even STM32duino-style):
drawn wires, with local labels only where pins are legitimately shared.
driven' because it's genuinely driven off-sheet, by the debug probe.
3. U1 pin numbers are REAL, verified against NXP's own S32K1xx Reference
NOTES:
10. ERC is clean except 4 EXPECTED findings (was 388 before a full pass -
is a known tool limitation, not a wiring bug. J2 SWCLK shows 'not
for alternator rectification) to LM74700-Q1 (correct: reverse-battery).
(passives). Fuses/connectors use other automotive standards, not AEC-Qxxx.
real S32K1xx Reference Manual before layout.
via NXP's S32 Design Studio + SDK over SWD (J2), not an Arduino sketch flow.
1. Power nets (+5V, +3V3, GND, VIN) use power symbols throughout; signal nets use
actually 5V. See README before wiring up 5V-logic shields/peripherals.
9. Q1 is PMV37ENEA (swapped from PMV230ENEA): same SOT-23 pinout/package,
datasheets this session (TI for U2/U3/U4, Nexperia for Q1) - not generic
2. U2/U3/U4/Q1 pin numbers are REAL, verified against actual manufacturer
package/AEC-Q100 qualification are also real and verified.
Grade 1 (ICs, -40..125C) - Q101 = AEC-Q101 (discretes) - Q200 = AEC-Q200
MCU CORE (NXP S32K1, 3.3V LOGIC)
POWER INPUT, REVERSE-BATTERY + TRANSIENT PROTECTION
see kicad-file-generation-gotchas memory for how): +5V/VDDA/U2-VIN each
Manual (64-pin LQFP - the 48-pin LQFP package considered earlier does not
LC filter/ferrite/FET - ERC can't trace power through passives, this
custom footprint built from TI's own package drawing (4225021/C 05/2022),
see build_u2_footprint.py, replaces the earlier wrong 4x4mm/11-pad guess.
rating with real margin at engine-bay temperatures.
NXP's own docs confirm the 'Arduino pin layout' is physical only. Programmed
7. IMPORTANT: MCU logic is 3.3V, not 5V. D0-D13/A0-A7 on J1 will not drive

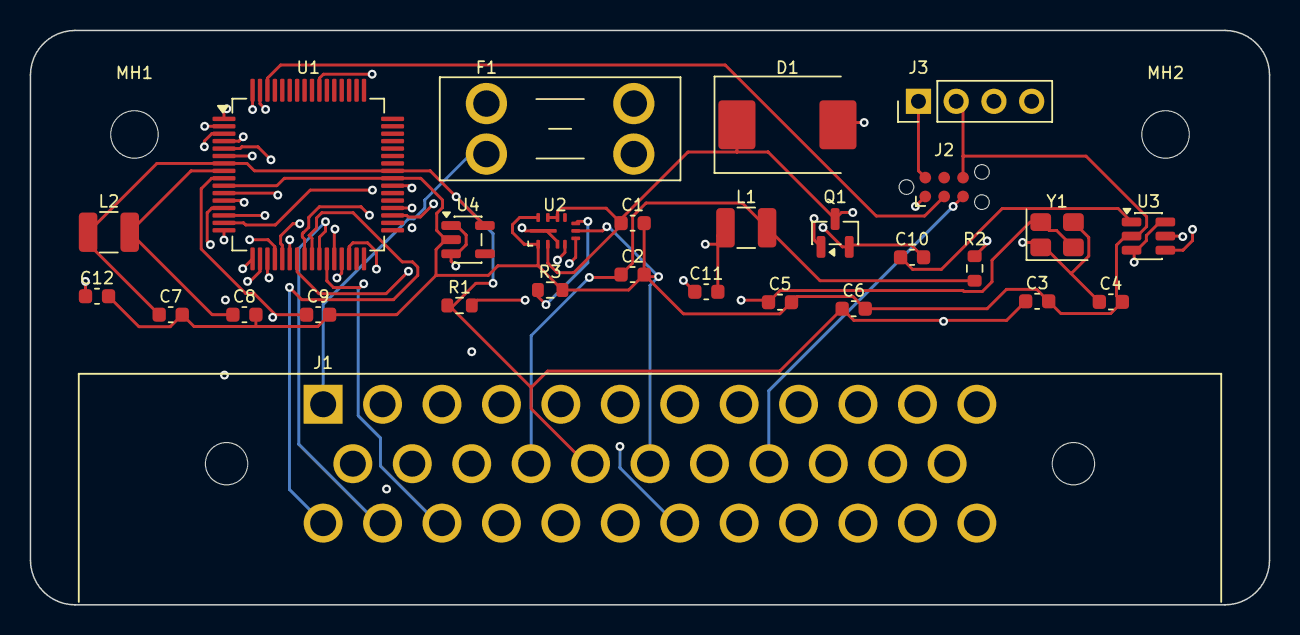
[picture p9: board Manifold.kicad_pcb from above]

Board: 4 copper layers, 83.4 x 38.7 mm, 30 parts (0 on the bottom side), 47 nets.

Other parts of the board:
MH1, MH2: MountingHole_3.2mm_M3

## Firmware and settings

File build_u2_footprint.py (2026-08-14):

"""
Builds a correct VQFN-12-HR (RNX0012C) footprint for U2 (LMR33630-Q1), replacing
the wrong bundled 4x4mm/11-pad placeholder that shipped in build_pcb.py.

Where these numbers came from: TI's own LMR33630-Q1 datasheet (SLVSFP4, package
drawing 4225021/C, 05/2022), pages "RNX0012C PACKAGE OUTLINE" and "RNX0012C
EXAMPLE BOARD LAYOUT" (rendered from lmr33630q1.pdf with PyMuPDF since the
printed dimension-chain text comes out scrambled through pdftotext on this
drawing - garbled enough that hand-transcribing it risked a genuinely wrong,
mis-pitched footprint on a 0.5mm-pitch part). Rather than trust either the
scrambled text OR eyeballed pixel positions off the rendered page image, the
land-pattern page's actual vector paths were pulled straight out of the PDF
with page.get_drawings(), filtered to the drawing's pad-outline blue
(0.0, 0.498, 1.0) stroke color, and each pad's rectangle recovered by
clustering nearby path segments - a computed number straight from the
manufacturer's own vector drawing (at a discovered 20x embedded scale factor,
confirmed by cross-checking against the printed "SCALE: 20X" caption and two
independent printed dimensions: pin12's pad height (1.826mm measured vs 1.825mm
printed) and the PKG-centerline-to-pin12 distance (0.788mm measured vs 0.7875mm
printed) both landed within 0.001mm of the OCR'd label - strong confirmation
the measurement pipeline is right), not a hand-measured guess.

This also corrects a real error carried in this project's memory/notes: the
established "U2 pin mapping" previously included a 13th pin "EP" (exposed
thermal pad). TI's own Pin Functions table (Table 5-1, Section 5) lists only
pins 1-12 with no EP row, and this land pattern page has exactly 12 pad
clusters, not 13 - this VQFN-HR variant has NO exposed pad at all. The EP
belief was wrong and is dropped here.

Real, non-uniform pad layout (confirmed independently three ways: printed
"4X 0.5" pitch labels, the datasheet's own pin table, and this direct vector
measurement) - NOT a simple evenly-spaced 3-pins-per-side QFN:
  - Left column (X=-0.9mm): pins 1,2,3,4 top to bottom, Y = -1.126, -0.475,
    0.175, 0.675mm. Gaps are 0.651/0.650/0.500mm - two wider 0.65mm gaps near
    the top (clearance for pin 12), then standard 0.5mm pitch at the bottom.
  - Right column (X=+0.9mm): pins 11,10,9,8 mirroring the left column exactly.
  - Bottom row (Y=1.400mm): pins 5,6,7 at X = -0.5, 0, +0.5mm.
  - Pin 12 (SW, the switch node): a single, taller pad at X=0, Y=-0.788mm,
    0.25 x 1.826mm - deliberately bigger than the other pads, consistent with
    it carrying the buck converter's full switching current.
Side/bottom pad size: 0.6mm (radial, long axis) x 0.25mm (tangential) - i.e.
horizontal 0.6x0.25mm for the left/right columns, vertical 0.25x0.6mm for the
bottom row (rotated 90 since the radial direction rotates with position).

Verify after running: `kicad-cli pcb upgrade` (or load in the KiCad footprint
editor) on the output file, then re-run build_pcb.py + run_drc.py.
"""
import os
import uuid

HERE = os.path.dirname(os.path.abspath(__file__))
OUT_DIR = os.path.join(HERE, "footprints", "TI_RNX0012C_VQFN-HR.pretty")
FP_NAME = "TI_RNX0012C_VQFN-HR-12_2x3mm_P0.5mm"
OUT_FILE = os.path.join(OUT_DIR, f"{FP_NAME}.kicad_mod")

# (pad number, x_mm, y_mm, size_x_mm, size_y_mm)
PADS = [
    (1, -0.9, -1.126, 0.6, 0.25),
    (2, -0.9, -0.475, 0.6, 0.25),
    (3, -0.9, 0.175, 0.6, 0.25),
    (4, -0.9, 0.675, 0.6, 0.25),
    (5, -0.5, 1.400, 0.25, 0.6),
    (6, 0.0, 1.400, 0.25, 0.6),
    (7, 0.5, 1.400, 0.25, 0.6),
    (8, 0.9, 0.675, 0.6, 0.25),
    (9, 0.9, 0.175, 0.6, 0.25),
    (10, 0.9, -0.475, 0.6, 0.25),
    (11, 0.9, -1.126, 0.6, 0.25),
    (12, 0.0, -0.788, 0.25, 1.826),
]

BODY_X = 2.0
BODY_Y = 3.0
COURTYARD_MARGIN = 0.25


def u():
    return str(uuid.uuid4())


def build():
    os.makedirs(OUT_DIR, exist_ok=True)
    lines = []
    lines.append(f'(footprint "{FP_NAME}"')
    lines.append('\t(version 20260206)')
    lines.append('\t(generator "build_u2_footprint.py")')
    lines.append('\t(generator_version "10.0")')
    lines.append('\t(layer "F.Cu")')
    lines.append(f'\t(uuid "{u()}")')
    lines.append('\t(descr "TI LMR33630-Q1, VQFN-HR-12 (RNX0012C), 2x3mm body, 0.5mm pitch, non-uniform pad spacing per TI package drawing 4225021/C 05/2022 - no exposed pad on this package variant")')
    lines.append('\t(tags "TI VQFN-HR RNX0012C LMR33630")')
    lines.append(f'\t(property "Reference" "REF**" (at 0 -2.2 0) (layer "F.SilkS") (uuid "{u()}")')
    lines.append('\t\t(effects (font (size 1 1) (thickness 0.15)))')
    lines.append('\t)')
    lines.append(f'\t(property "Value" "{FP_NAME}" (at 0 2.2 0) (layer "F.Fab") (uuid "{u()}")')
    lines.append('\t\t(effects (font (size 1 1) (thickness 0.15)))')
    lines.append('\t)')

    # Body outline on F.Fab
    hx, hy = BODY_X / 2, BODY_Y / 2
    corners = [(-hx, -hy), (hx, -hy), (hx, hy), (-hx, hy), (-hx, -hy)]
    for (x0, y0), (x1, y1) in zip(corners, corners[1:]):
        lines.append(f'\t(fp_line (start {x0} {y0}) (end {x1} {y1}) (stroke (width 0.1) (type solid)) (layer "F.Fab") (uuid "{u()}"))')

    # Courtyard
    cx, cy = hx + COURTYARD_MARGIN, hy + COURTYARD_MARGIN
    ccorners = [(-cx, -cy), (cx, -cy), (cx, cy), (-cx, cy), (-cx, -cy)]
    for (x0, y0), (x1, y1) in zip(ccorners, ccorners[1:]):
        lines.append(f'\t(fp_line (start {x0} {y0}) (end {x1} {y1}) (stroke (width 0.05) (type solid)) (layer "F.CrtYd") (uuid "{u()}"))')

    # Pin-1 marker: small silkscreen line clear of pin 1's pad, near the top-left corner
    lines.append(f'\t(fp_line (start {-hx} {-hy - 0.3}) (end {-hx + 0.3} {-hy - 0.3}) (stroke (width 0.12) (type solid)) (layer "F.SilkS") (uuid "{u()}"))')
    lines.append(f'\t(fp_line (start {-hx} {-hy - 0.3}) (end {-hx} {-hy}) (stroke (width 0.12) (type solid)) (layer "F.SilkS") (uuid "{u()}"))')

    for num, x, y, sx, sy in PADS:
        lines.append(
            f'\t(pad "{num}" smd roundrect (at {x} {y}) (size {sx} {sy}) '
            f'(layers "F.Cu" "F.Paste" "F.Mask") (roundrect_rratio 0.25) (uuid "{u()}"))'
        )

    # Real-dimension placeholder body (see build_3d_models.py) - this custom
    # footprint never had a 3D model at all until now, since it's hand-built
    # from TI's package drawing rather than downloaded from a library that
    # would normally ship one alongside it.
    lines.append(
        '\t(model "${KIPRJMOD}/3dmodels/TI_RNX0012C_VQFN-HR-12_2x3mm.step"\n'
        '\t\t(offset (xyz 0 0 0))\n'
        '\t\t(scale (xyz 1 1 1))\n'
        '\t\t(rotate (xyz 0 0 0))\n'
        '\t)'
    )
    lines.append(')')
    content = "\n".join(lines) + "\n"
    with open(OUT_FILE, "w", newline="\n") as f:
        f.write(content)
    print("Wrote", OUT_FILE)


if __name__ == "__main__":
    build()

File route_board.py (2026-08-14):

"""
Routes Manifold.kicad_pcb with FreeRouting, then adds GND/+3V3 zone
pours on top of the finished routing.

Four steps, each independently verifiable:
  1. Export a Specctra .dsn from the board using KiCad's OWN Python API
     (pcbnew.ExportSpecctraDSN) - the real exporter built into pcbnew, not a
     reimplementation. This runs under KiCad's *bundled* Python interpreter
     (which has the `pcbnew` module), not the Python running this script.
  2. Run FreeRouting headless (java -jar, no GUI) on the .dsn to produce a
     routed .ses session file.
  3. Import that .ses back into the board with KiCad's own
     pcbnew.ImportSpecctraSES and save.
  4. Add GND (In1.Cu) and +3V3 (In2.Cu) zone pours and fill them - done
     AFTER routing, not before, so they're purely additive copper on an
     already-100%-connected-by-traces board rather than something any net's
     connectivity actually depends on (see add_and_fill_zones' own comment
     for why doing this before routing backfired).

Requires:
  - tools/freerouting-2.2.4.jar (see README - Java + FreeRouting setup)
  - KiCad's bundled Python at KICAD_PYTHON below (ships with any KiCad
    install; distinct from the system Python used to run this file)

This does NOT run kicad-cli DRC itself - run run_drc.py afterward to verify
the routed result (clearance, unrouted-net count, etc).
"""
import os
import subprocess
import sys

HERE = os.path.dirname(os.path.abspath(__file__))
PCB = os.path.join(HERE, "Manifold.kicad_pcb")
DSN = os.path.join(HERE, "Manifold.dsn")
SES = os.path.join(HERE, "Manifold.ses")
FREEROUTING_JAR = os.path.join(HERE, "tools", "freerouting-2.2.4.jar")

KICAD_PYTHON = r"C:\Program Files\KiCad\10.0\bin\python.exe"
JAVA_CANDIDATES = [
    r"C:\Program Files\Eclipse Adoptium\jre-25.0.3.9-hotspot\bin\java.exe",
]

# Autorouter effort: cap passes so a bad/congested board fails fast instead of
# spinning forever, rather than trying to tune "good enough" up front.
# `-oit 0` disables FreeRouting's "stop early if the score hasn't improved
# much in the last 10 passes" behavior, so it keeps trying up to MAX_PASSES
# instead of settling for a plateau - cheap insurance on a small board like
# this one, and matters more now that no zones exist yet at routing time
# (see add_and_fill_zones below) - this is genuinely just ordinary trace
# routing, same regime that's reliably reached 0 unrouted before.
MAX_PASSES = 60
OPTIMIZATION_IMPROVEMENT_THRESHOLD = 0


def find_java():
    import shutil
    exe = shutil.which("java")
    if exe:
        return exe
    for candidate in JAVA_CANDIDATES:
        if os.path.isfile(candidate):
            return candidate
    raise SystemExit("java not found - see README for the Java + FreeRouting setup")


def run_kicad_python(label, script):
    result = subprocess.run([KICAD_PYTHON, "-c", script], capture_output=True, text=True)
    print(result.stdout.strip())
    if result.returncode != 0:
        print(result.stderr.strip(), file=sys.stderr)
        raise SystemExit(f"{label} failed (exit {result.returncode})")


def export_dsn():
    if not os.path.isfile(KICAD_PYTHON):
        raise SystemExit(f"KiCad's bundled Python not found at {KICAD_PYTHON}")
    # repr() on every embedded path, not an f-string splice - Windows paths
    # contain sequences like "\Users" that a plain (non-raw) generated string
    # literal misreads as a unicode escape (\U...); repr() escapes correctly
    # no matter where the path lands in the generated script text.
    run_kicad_python("DSN export", f'''
import pcbnew
board = pcbnew.LoadBoard({PCB!r})
ok = pcbnew.ExportSpecctraDSN(board, {DSN!r})
print("DSN export:", "OK" if ok else "FAILED", "->", {DSN!r})
if not ok:
    raise SystemExit(1)
''')


def run_freerouting():
    java = find_java()
    if not os.path.isfile(FREEROUTING_JAR):
        raise SystemExit(f"FreeRouting jar not found at {FREEROUTING_JAR} - see README")
    cmd = [java, "-jar", FREEROUTING_JAR, "-de", DSN, "-do", SES,
           "-mp", str(MAX_PASSES), "-oit", str(OPTIMIZATION_IMPROVEMENT_THRESHOLD),
           "--gui.enabled=false"]
    print("Running:", " ".join(cmd))
    result = subprocess.run(cmd, capture_output=True, text=True)
    # FreeRouting logs to stdout even on success - keep the tail, it's where
    # the final pass/route-completion summary shows up.
    print("\n".join(result.stdout.strip().splitlines()[-40:]))
    if result.returncode != 0:
        print(result.stderr.strip()[-2000:], file=sys.stderr)
        raise SystemExit(f"FreeRouting failed (exit {result.returncode})")
    if not os.path.isfile(SES):
        raise SystemExit("FreeRouting exited OK but did not produce a .ses file")


def import_ses():
    run_kicad_python("SES import", f'''
import pcbnew
board = pcbnew.LoadBoard({PCB!r})
ok = pcbnew.ImportSpecctraSES(board, {SES!r})
print("SES import:", "OK" if ok else "FAILED")
if not ok:
    raise SystemExit(1)
board.Save({PCB!r})
print("Saved routed board to", {PCB!r})
''')


ZONE_INSET_MM = 0.5   # clearance from Edge.Cuts
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

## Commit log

2026-08-14 Manifold PCB: Arduino Nano-inspired automotive board, NXP S32K144
    Full script-driven KiCad project (schematic, PCB, and routing all
    generated from build_schematic.py/build_pcb.py/route_board.py, never
    hand-edited). Real, AEC-Q-qualified parts throughout, verified against
    manufacturer datasheets: NXP S32K144 MCU, TI LM74700-Q1/LMR33630-Q1/
    TLV733P-Q1 power stage, Nexperia PMV37ENEA reverse-battery protection,
    TE AMPSEAL 776180-1 35-position connector. 4-layer, DRC-clean, fully
    routed.
    [Manifold.kicad_pcb, Manifold.kicad_sch, TI_RNX0012C_VQFN-HR-12_2x3mm.step]
2026-08-14 Add build.py: one-command pipeline (schematic -> PCB -> route -> DRC)
    Chains the existing build_schematic.py/build_pcb.py/route_board.py/
    run_drc.py scripts in the order they actually have to run, with a
    --skip-route flag for iterating without the slow FreeRouting pass.
    Doesn't reimplement anything - same real scripts, same real behavior.
    [build.py]
2026-09-27 Ignore regenerated fab-output artifacts
    Same convention as thermo-pcb: Gerbers/drill/zip/render are derived from
    Manifold.kicad_pcb on demand, not hand-authored source.
